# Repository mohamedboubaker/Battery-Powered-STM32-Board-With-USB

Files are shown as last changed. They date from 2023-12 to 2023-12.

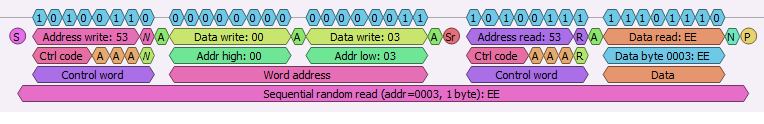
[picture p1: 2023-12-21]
Hardware/Pictures/i2c read.png

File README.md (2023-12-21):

# Battery-Powered-STM32-Board-With-USB
An STM32 board that runs on a battery with MCP73831 and is easily programmable with USB thanks to the CP2102 USB-to-UART chip. 

Project Documentation: https://embeddedprojects101.com/design-a-battery-powered-stm32-board-with-usb/

<p align="center">
  
</p>

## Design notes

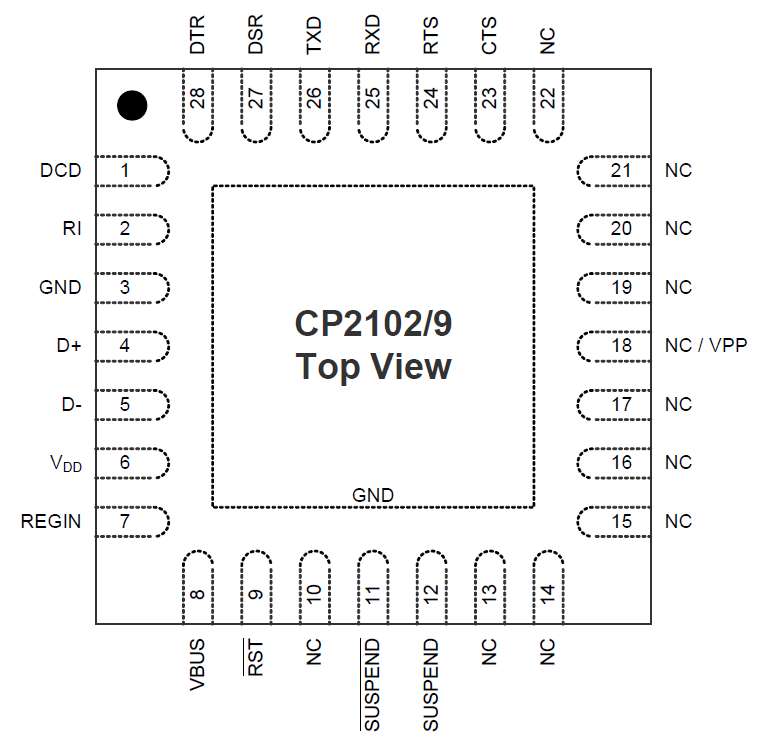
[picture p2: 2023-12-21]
Hardware/Pictures/CP21021 top view.png

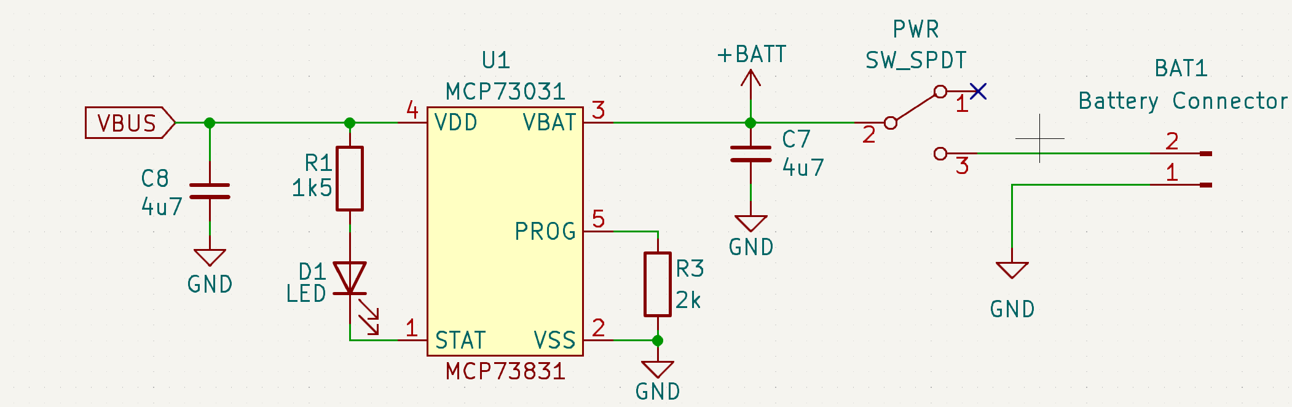
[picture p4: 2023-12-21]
Hardware/Pictures/MCP73831-battery-management-circuit.png

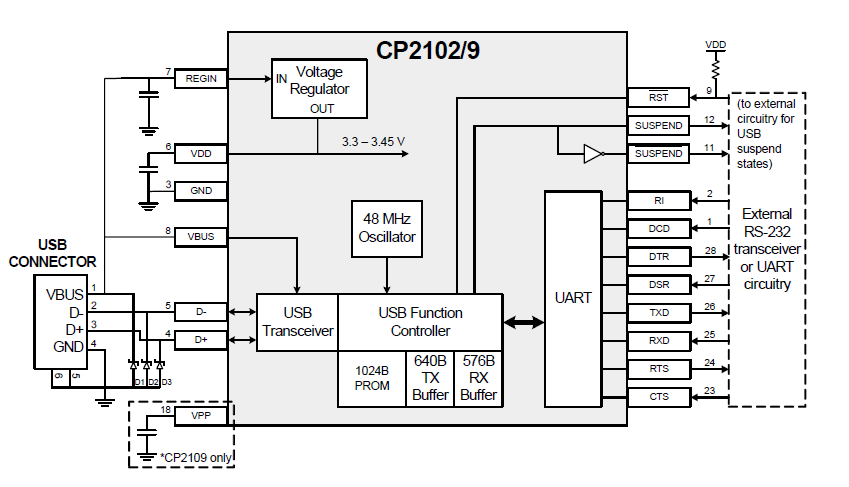
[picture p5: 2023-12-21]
Hardware/Pictures/CP2102 block diagram.png

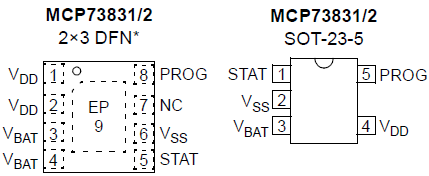
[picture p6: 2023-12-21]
Hardware/Pictures/MCP73831 packages.png

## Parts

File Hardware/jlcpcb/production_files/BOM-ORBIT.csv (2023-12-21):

Comment | Designator | Footprint | LCSC
560k | R7 | R_0603_1608Metric | C101109
8MHz | U10 | Crystal_SMD_5032-2Pin_5.0x3.2mm | C115962
BOOT0_SW | BOOT0,PWR1 | K3-1270L-F1 | C145857
100n | C19,C21,C24,C3,C4,C5,C6,C9 | C_0603_1608Metric | C14663
1uF | C23 | C_0603_1608Metric | C15849
Battery Connector | BAT1 | JST_PH_B2B-PH-SM4-TB_1x02-1MP_P2.00mm_Vertical | C160352
10p | C18 | C_0603_1608Metric | C1634
30p | C11,C12 | C_0603_1608Metric | C1658
4u7 | C2,C20,C7,C8 | C_0603_1608Metric | C19666
10uF | C14 | C_0603_1608Metric | C19702
1K | R11 | R_0603_1608Metric | C21190
1k5 | R1,R4,R5 | R_0603_1608Metric | C22843
2k | R3 | R_0603_1608Metric | C22975
STM32F030C8Tx | U16 | LQFP-48_7x7mm_P0.5mm | C23922
100K | R12,R6,R8 | R_0603_1608Metric | C25803
10K | R2 | R_0603_1608Metric | C25804
USB Connector | USB1 | MINI-USB-SMD_MINI-5PTP | C2681563
TPS63802DLAR | U15 | TPS63802DLAR | C2845237
RESET | SW1,SW2 | SW_Push_1P1T_NO_CK_KSC6xxJ | C318884
2k2 | R10,R9 | R_0603_1608Metric | C4190
MCP73031 | U1 | SOT-23-5 | C424093
22uF | C13 | C_0603_1608Metric | C59461
AT24C128C | U17 | SOIC127P600X175-8N | C6478
CP2102-GMR | U22 | QFN28G_0.5-5X5MM | C6568
0.47uH | L1 | INDC2016X120N | C668312
LED2 | D3 | LED_0603_1608Metric | C72041
LED | D1,D2 | LED_0603_1608Metric | C72043
East Connector | J2 | PinHeader_1x08_P2.54mm_Vertical
MountingHole | H2 | MountingHole_2.5mm_Pad_Via
MountingHole | H1 | MountingHole_2.5mm_Pad_Via
MountingHole | H4 | MountingHole_2.5mm_Pad_Via
MountingHole | H3 | MountingHole_2.2mm_M2_Pad_Via
West Connector | J1 | PinHeader_1x08_P2.54mm_Vertical

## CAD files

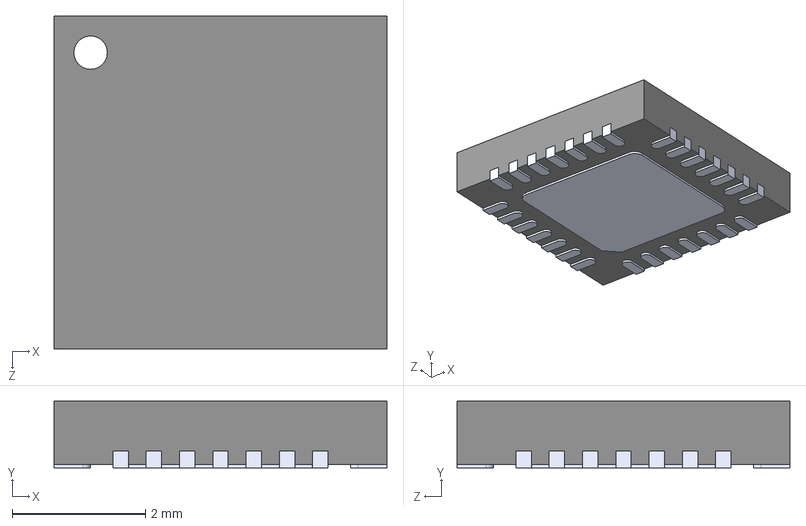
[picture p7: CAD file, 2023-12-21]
Hardware/Components 3D Models/INTERFACE-CP2102-GMR_QFN28_.step
5.00 x 1.00 x 5.00 mm

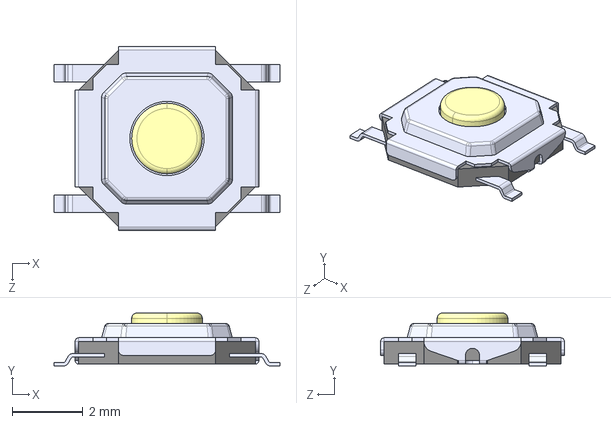
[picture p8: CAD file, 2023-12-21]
Hardware/Components 3D Models/SKQGADE010--3DModel-STEP-56544.STEP
6.40 x 1.50 x 5.20 mm

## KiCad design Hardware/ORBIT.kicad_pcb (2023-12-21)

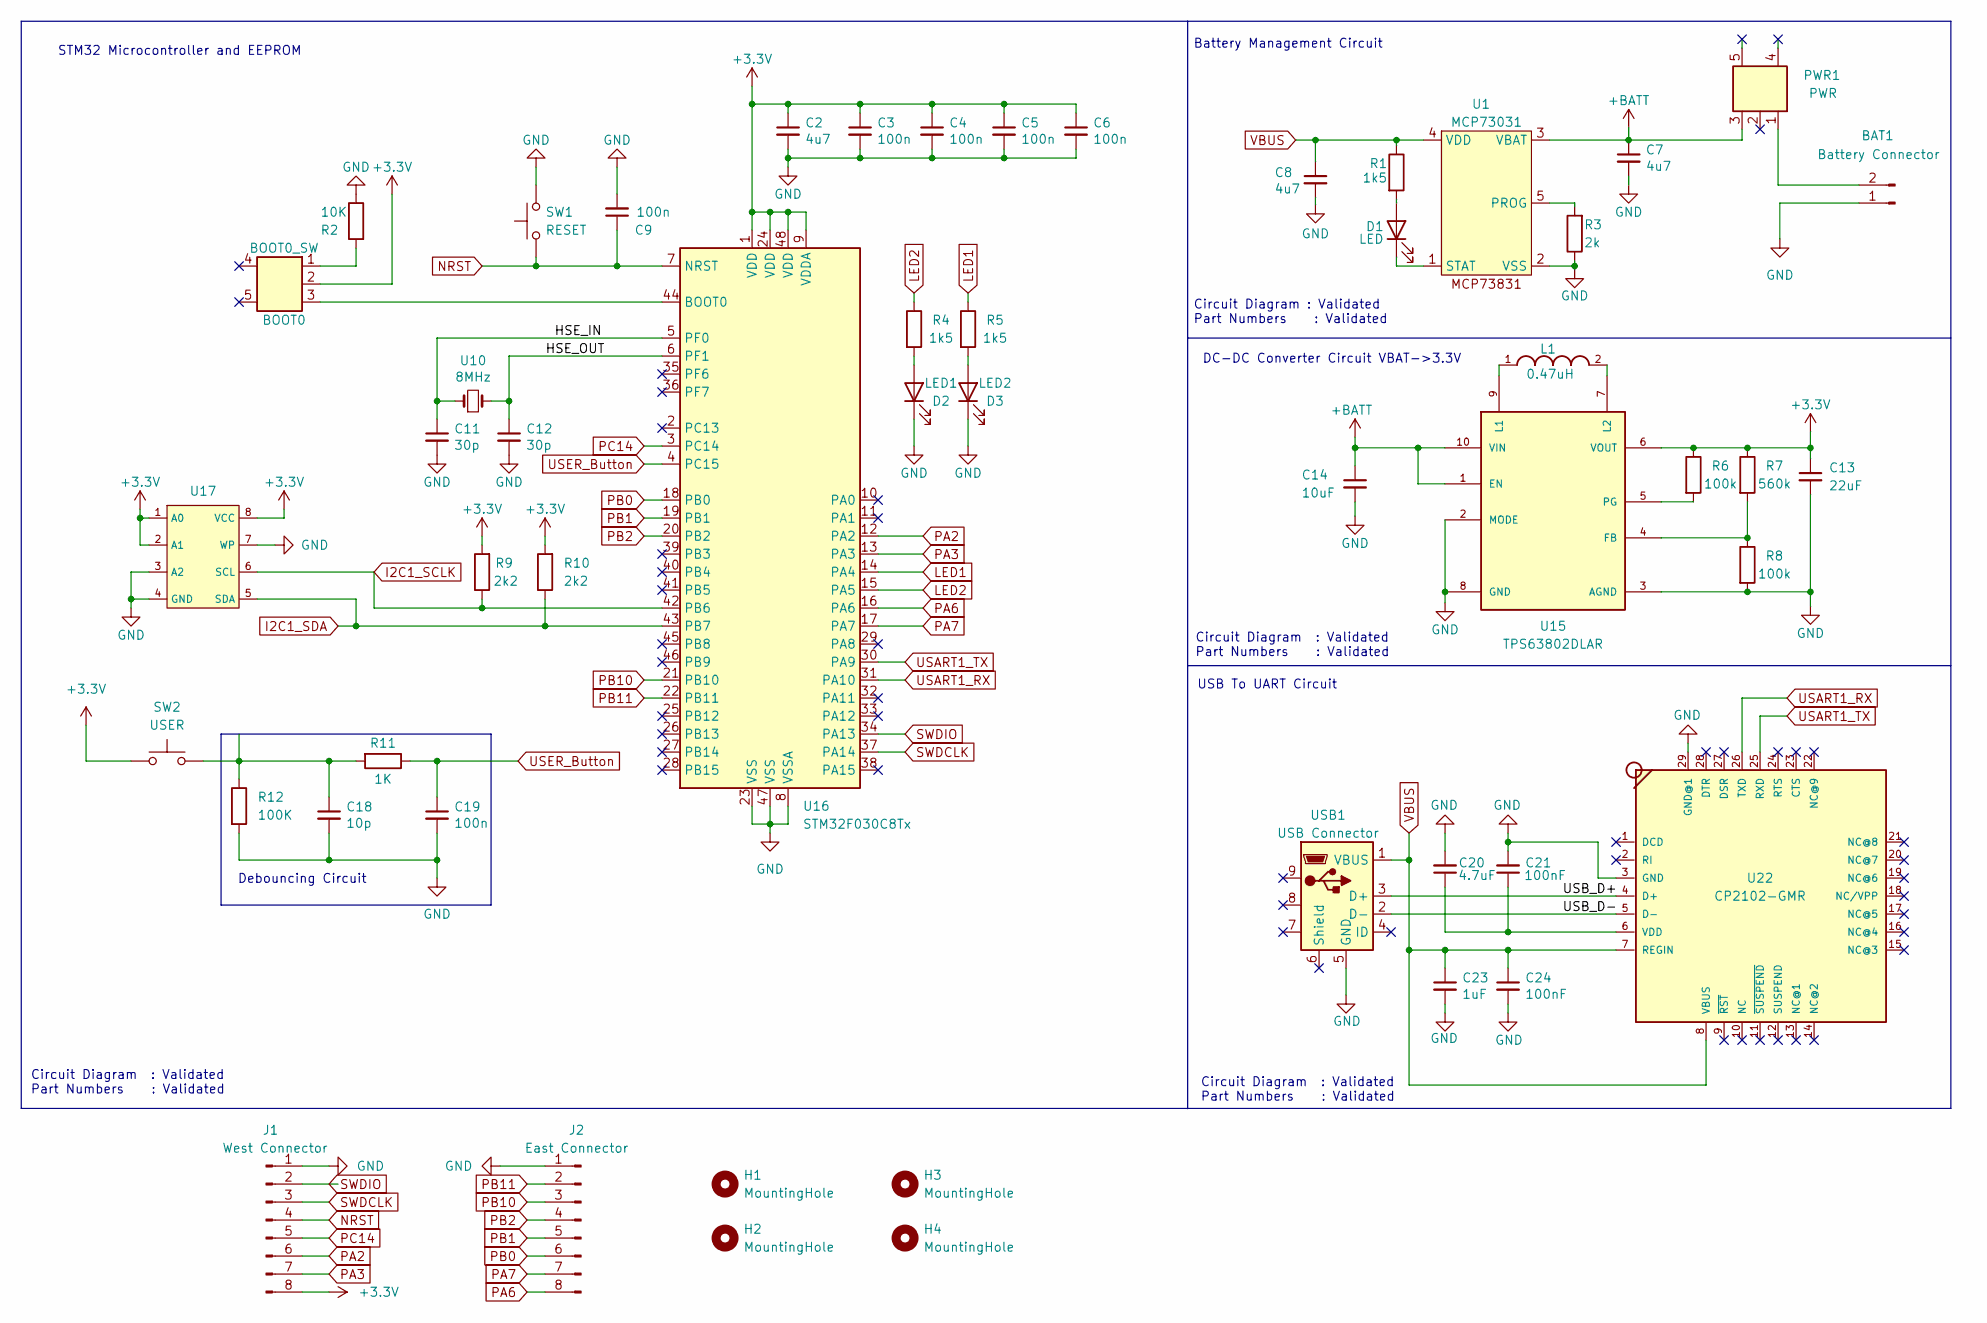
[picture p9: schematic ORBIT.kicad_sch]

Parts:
BAT1: Battery Connector; JST_PH_B2B-PH-SM4-TB_1x02-1MP_P2.00mm_Vertical; LCSC Part # C160352
BOOT0: BOOT0_SW; K3-1270L-F1; LCSC Part # C145857
C2, C7, C8: 4u7; C_0603_1608Metric; LCSC Part # C19666
C3, C4, C5, C6, C9, C19: 100n; C_0603_1608Metric; LCSC Part # C14663
C11, C12: 30p; C_0603_1608Metric; LCSC Part # C1658
C13: 22uF; C_0603_1608Metric; LCSC Part # C59461
C14: 10uF; C_0603_1608Metric; LCSC Part # C19702
C18: 10p; C_0603_1608Metric; LCSC Part # C1634
C20: 4.7uF; C_0603_1608Metric; LCSC Part # C19666
C21, C24: 100nF; C_0603_1608Metric; LCSC Part # C14663
C23: 1uF; C_0603_1608Metric; LCSC Part # C15849
D1: LED; LED_0603_1608Metric; LCSC Part # C72043
D2: LED1; LED_0603_1608Metric; LCSC Part # C72043
D3: LED2; LED_0603_1608Metric; LCSC Part # C72041
H1, H2, H4: MountingHole; MountingHole_2.5mm_Pad_Via
H3: MountingHole; MountingHole_2.2mm_M2_Pad_Via
J1: West Connector; PinHeader_1x08_P2.54mm_Vertical
J2: East Connector; PinHeader_1x08_P2.54mm_Vertical
L1: 0.47uH; INDC2016X120N; LCSC Part # C668312
PWR1: PWR; K3-1270L-F1; LCSC Part # C145857
R1, R4, R5: 1k5; R_0603_1608Metric; LCSC Part # C22843
R2: 10K; R_0603_1608Metric; LCSC Part # C25804
R3: 2k; R_0603_1608Metric; LCSC Part # C22975
R6, R8: 100k; R_0603_1608Metric; LCSC Part # C25803
R7: 560k; R_0603_1608Metric; LCSC Part # C101109
R9, R10: 2k2; R_0603_1608Metric; LCSC Part # C4190
R11: 1K; R_0603_1608Metric; LCSC Part # C21190
R12: 100K; R_0603_1608Metric; LCSC Part # C25803
SW1: RESET; SW_Push_1P1T_NO_CK_KSC6xxJ; LCSC Part # C318884
SW2: USER; SW_Push_1P1T_NO_CK_KSC6xxJ; LCSC Part # C318884
U1: MCP73031; SOT-23-5; LCSC Part # C424093
U10: 8MHz; Crystal_SMD_5032-2Pin_5.0x3.2mm; LCSC Part # C115962
U15: TPS63802DLAR; LCSC Part # C2845237
U16: STM32F030C8Tx; LQFP-48_7x7mm_P0.5mm; LCSC Part # C23922
U17: SOIC127P600X175-8N
U22: CP2102-GMR; QFN28G_0.5-5X5MM; LCSC Part# C6568
USB1: USB Connector; MINI-USB-SMD_MINI-5PTP; LCSC Part # C2681563

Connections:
+3.3V: BOOT0.2, C2.1, C3.1, C4.1, C5.1, C6.1, C13.1, J1.8, R6.1, R7.1, R9.2, R10.2, SW2.1, U15.6 (VOUT), U16.1 (VDD), U16.9 (VDDA), U16.24 (VDD), U16.48 (VDD), U17.1 (A0), U17.2 (A1), U17.8 (VCC)
+BATT: C7.1, C14.1, PWR1.3, U1.3 (VBAT), U15.1 (EN), U15.10 (VIN)
/HSE_IN: C11.1, U10.1, U16.5 (PF0)
/HSE_OUT: C12.1, U10.2, U16.6 (PF1)
/USB_D+: U22.4 (D+), USB1.3 (D+)
/USB_D-: U22.5 (D-), USB1.2 (D-)
GND: BAT1.1, C2.2, C3.2, C4.2, C5.2, C6.2, C7.2, C8.2, C9.2, C11.2, C12.2, C13.2, C14.2, C18.2, C19.2, C20.2, C21.2, C23.2, C24.2, D2.1 (K), D3.1 (K), J1.1, J2.1, R2.1, R3.1, R8.2, R12.2, SW1.2, U1.2 (VSS), U15.2 (MODE), U15.3 (AGND), U15.8 (GND), U16.8 (VSSA), U16.23 (VSS), U16.47 (VSS), U17.3 (A2), U17.4 (GND), U17.7 (WP), U22.3 (GND), U22.29 (GND@1), USB1.5 (GND)
I2C1_SCLK: R9.1, U16.42 (PB6), U17.6 (SCL)
I2C1_SDA: R10.1, U16.43 (PB7), U17.5 (SDA)
LED1: R5.1, U16.14 (PA4)
LED2: R4.1, U16.15 (PA5)
NRST: C9.1, J1.4, SW1.1, U16.7 (NRST)
unnamed: BAT1.2, PWR1.1
unnamed: BOOT0.1, R2.2
unnamed: C18.1, R11.2, R12.1, SW2.2
unnamed: D1.2 (A), R1.2
unnamed: D1.1 (K), U1.1 (STAT)
unnamed: D2.2 (A), R4.2
unnamed: D3.2 (A), R5.2
unnamed: R3.2, U1.5 (PROG)
unnamed: R7.2, R8.1, U15.4 (FB)
unnamed: L1.1, U15.9 (L1)
unnamed: L1.2, U15.7 (L2)
unnamed: R6.2, U15.5 (PG)
unnamed: BOOT0.3, U16.44 (BOOT0)
unnamed: C20.1, C21.1, U22.6 (VDD)
PA2: J1.6, U16.12 (PA2)
PA3: J1.7, U16.13 (PA3)
PA6: J2.8, U16.16 (PA6)
PA7: J2.7, U16.17 (PA7)
PB0: J2.6, U16.18 (PB0)
PB1: J2.5, U16.19 (PB1)
PB2: J2.4, U16.20 (PB2)
PB10: J2.3, U16.21 (PB10)
PB11: J2.2, U16.22 (PB11)
PC14: J1.5, U16.3 (PC14)
SWDCLK: J1.3, U16.37 (PA14)
SWDIO: J1.2, U16.34 (PA13)
USART1_RX: U16.31 (PA10), U22.26 (TXD)
USART1_TX: U16.30 (PA9), U22.25 (RXD)
USER_Button: C19.1, R11.1, U16.4 (PC15)
VBUS: C8.1, C23.1, C24.1, R1.1, U1.4 (VDD), U22.7 (REGIN), U22.8 (VBUS), USB1.1 (VBUS)

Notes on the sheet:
Circuit Diagram : Validated Part Numbers : Validated
Battery Management Circuit
USB To UART Circuit
Debouncing Circuit
STM32 Microcontroller and EEPROM
Circuit Diagram : Validated Part Numbers : Validated
DC-DC Converter Circuit VBAT->3.3V

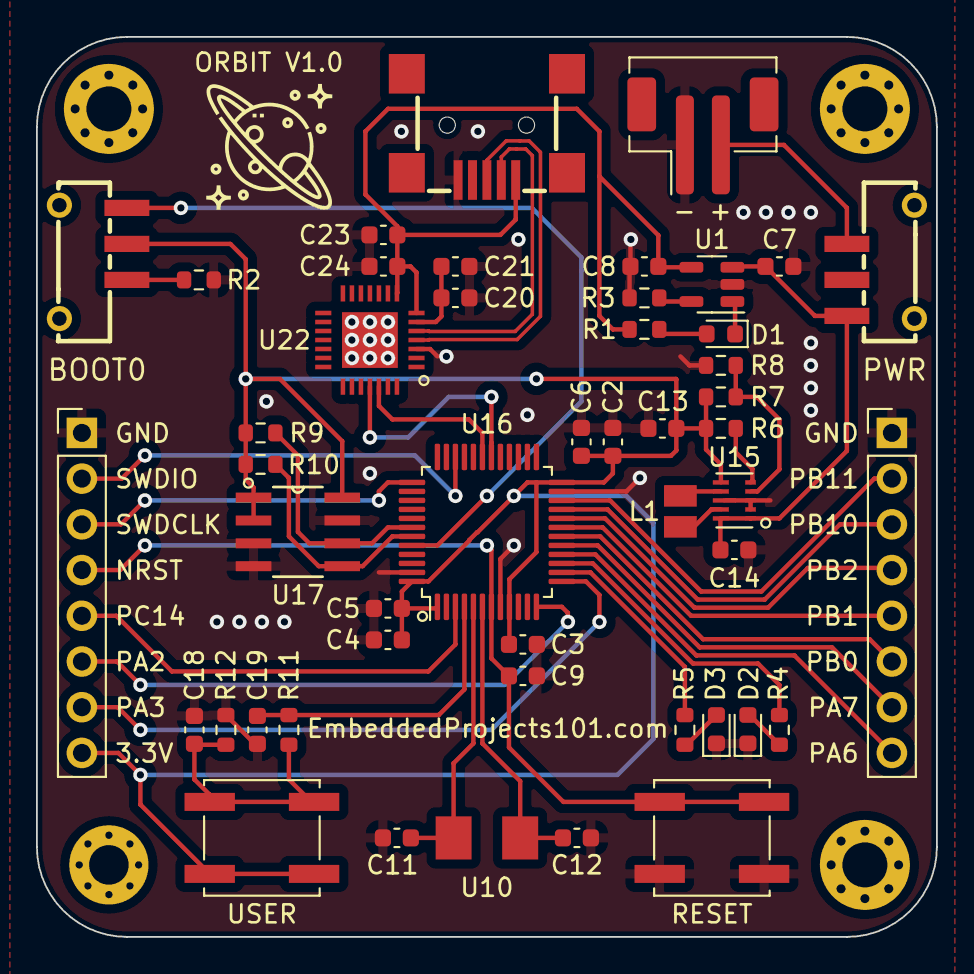
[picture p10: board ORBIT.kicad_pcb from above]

Board: 2 copper layers, 50.0 x 50.0 mm, 53 parts (0 on the bottom side), 42 nets.

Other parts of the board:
O: LOGO

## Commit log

2023-12-21 all components in the final positioned
    [ORBIT.kicad_pcb]
2023-12-21 Version 1.0
    [BOM-ORBIT.csv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]
